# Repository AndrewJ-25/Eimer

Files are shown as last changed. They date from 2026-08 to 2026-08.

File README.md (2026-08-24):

# Eimer
Eimer is a wearable RP2040 devboard!

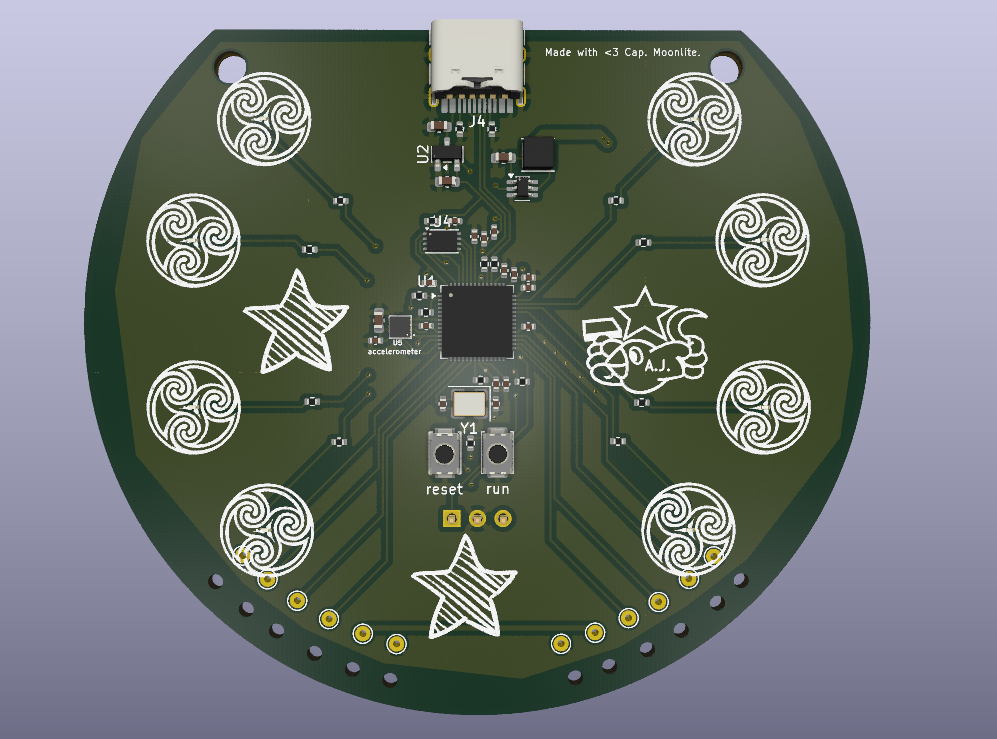
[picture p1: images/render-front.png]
front view

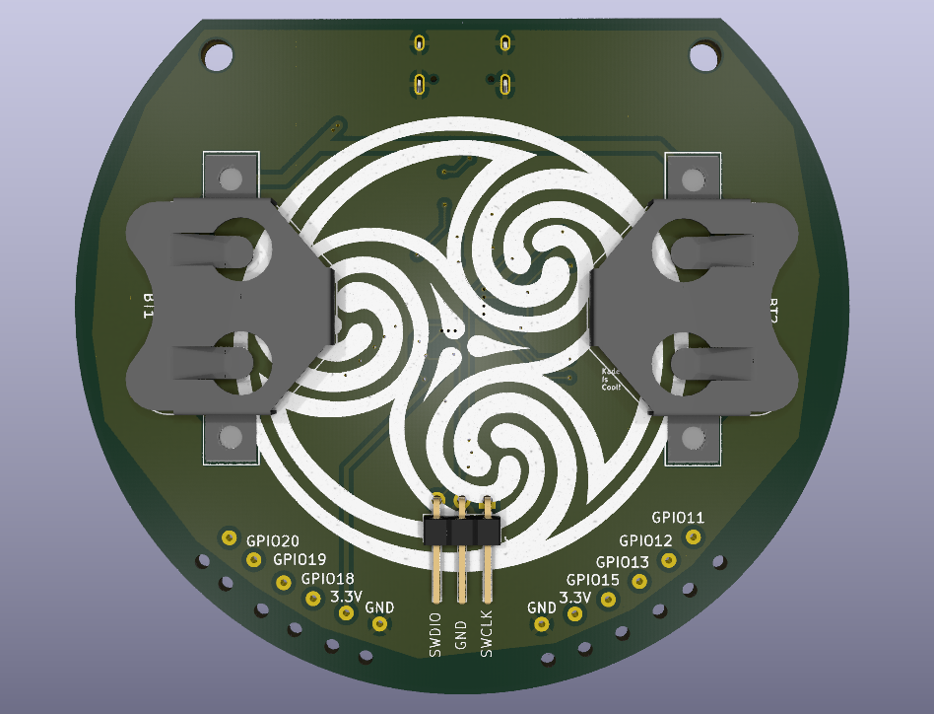
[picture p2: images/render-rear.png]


## Description and Features

A multi-axis accelerometer, 8 LEDs and 8 GPIO pads make Eimer an ideal wearable device. Solder pads are accompanied by holes to run the wire through, so there is no strain on the solder joint.

Eimer can be programmed using Arduino framework. Two mounting holes can be attached to a lanyard necklace, or safety pins.

Eimer can be powered with USB C or two CR2032 button cells (the board will work with one button cell, with a shorter battery life). Important note: do not plug in USB while cells are inserted!

I designed Eimer to get more comfortable with SMD and to learn more about MCUs. I started this project by following a tutorial posted in Hackclub Macondo before customising it.

The name comes from Irish mythology:)

## Assembly

All components can be soldered on a hotplate, except the coin cell holders which require hand-soldering.

## Schematic

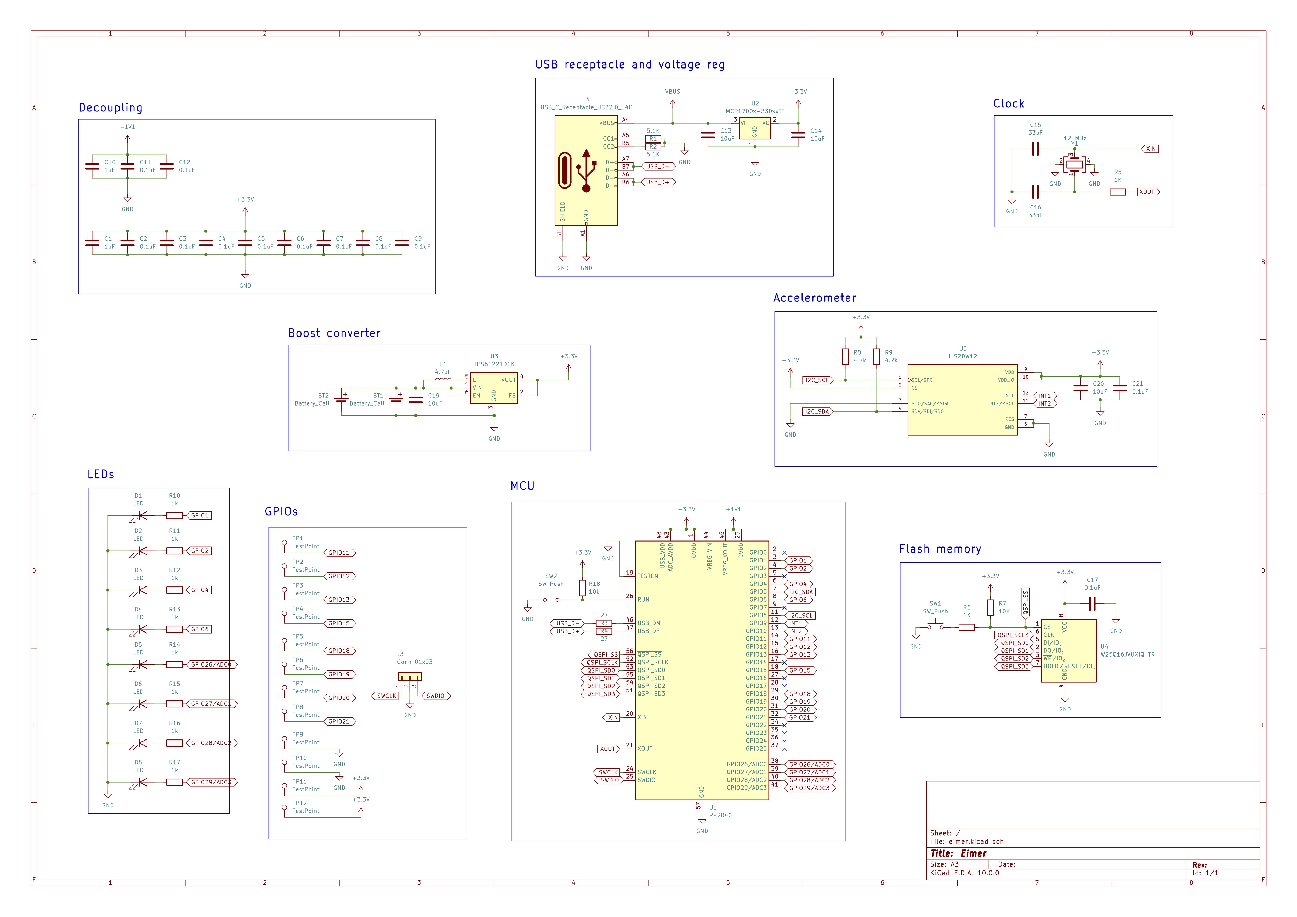
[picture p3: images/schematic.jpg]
schematic


## PCB

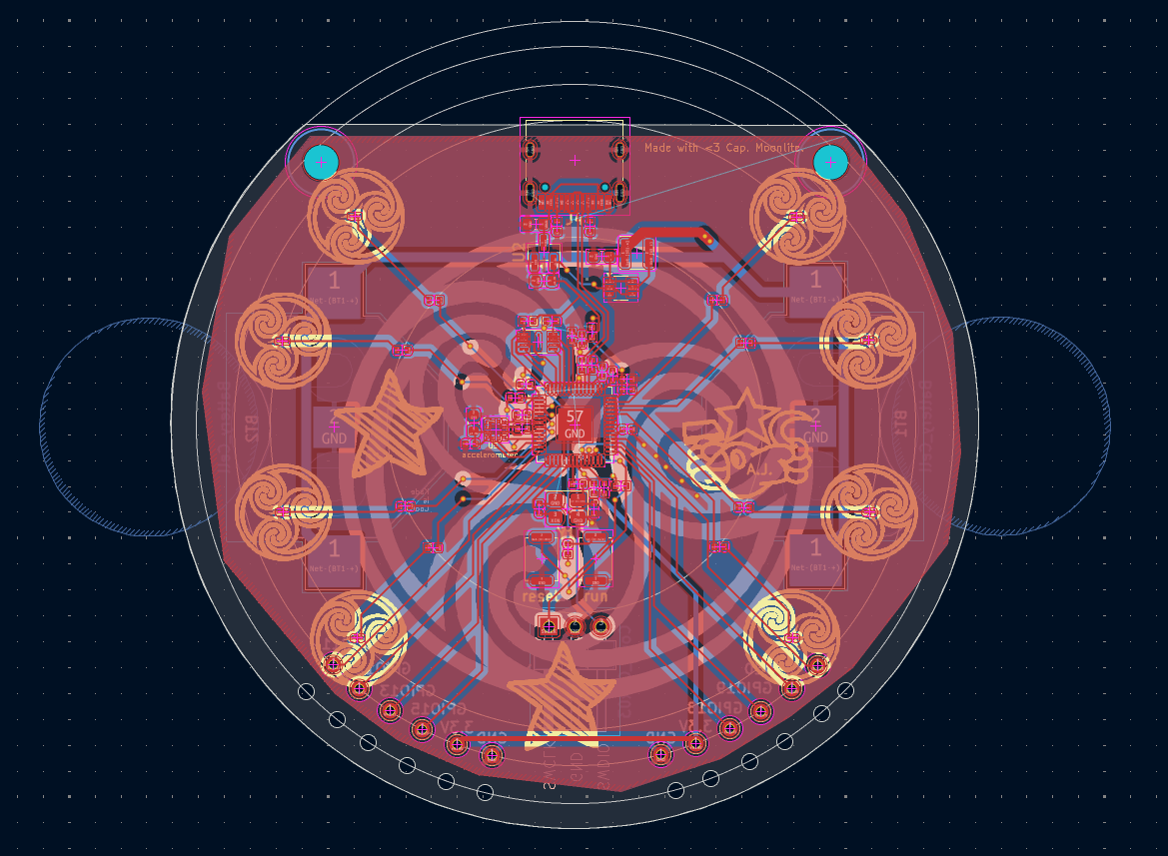
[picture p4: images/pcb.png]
pcb


## BOM

|Designator |Footprint |Quantity|Description|Suggested source|Total cost, £|
|---|---|---|---|---|--|
|BT1, BT2 |BatteryHolder_Multicomp_BC-2001_1x2032 |2 |CR2032 cell holder|https://www.aliexpress.com/item/1005010097971513.html|2.00|
|C1, C10 |0402 |2 |1uF capacitor|https://www.aliexpress.com/item/32435282135.html|0.67|
|C11, C12, C17, C2, C21, C3, C4, C5, C6, C7, C8, C9 |0402 |12 |0.1uF capacitor|https://www.aliexpress.com/item/32435282135.html|0.67
|C13, C14, C19, C20 |0603 |4 |10uF capacitor|https://www.aliexpress.com/item/1005007404529007.html|1.83|
|C15, C16 |0402 |2 |33pF capacitor|https://www.aliexpress.com/item/1005002960548572.html|1.27|
|D1, D2, D3, D4, D5, D6, D7, D8 |0201 |8 |LED green|https://www.aliexpress.com/item/1005007406675682.html|5.05|
|J3 |PinHeader_1x03_P2.54mm_Horizontal |1 |1x3 horizontal pin header| https://www.aliexpress.com/item/1005007569841697.html|0.55|
|J4 |USB_C_Receptacle_HRO_TYPE-C-31-M-12 |1 |USBC Receptacle|https://www.aliexpress.com/item/1005008805157100.html|1.04|
|L1 |L_APV_ANR3015 |1 |4.7uH inductor|https://www.aliexpress.com/item/1005001699576419.html|1.14|
|R1, R2 |0402 |2 |5.1K resistor|https://www.aliexpress.com/item/4001321720241.html (multipack includes all required resistor values)|1.86|
|R10, R11, R12, R13, R14, R15, R16, R17, R5, R6 |0402 |10 |1k resistor|-|-|
|R18, R7 |0402 |2 |10k resistor|-|-|
|R3, R4 |0402 |2 |27ohm resistor|-|-|
|R8, R9 |0402 |2 |4.7k resistor|-|-|
|RESET, RUN |SW_Push_SPST_NO_Alps_SKRK |2 |Push switch|https://jlcpcb.com/partdetail/XUNPU-TS_1088AR02016/C720477|1.00|
|U1 |QFN-56-1EP_7x7mm_P0.4mm_EP3.2x3.2mm |1 |RP2040 MCU chip|https://www.aliexpress.com/item/1005007275652762.html|3.46|
|U2 |SOT-23 |1 |MCP1700x-330xxTT voltage regulator|https://www.aliexpress.com/item/32808973510.html|0.99|
|U3 |Texas_R-PDSO-G6 |1 |TPS61221DCK boost converter|https://www.aliexpress.com/item/1005012857789997.html|3.69|
|U4 |Winbond_USON-8-1EP_3x2mm_P0.5mm_EP0.2x1.6mm|1 |W25Q16JVUXIQ TR flash memory|https://www.aliexpress.com/item/1005012822339773.html|5.55|
|U5 |LIS2DW12 |1 |LIS2DW12 accelerometer|https://www.aliexpress.com/item/1005009164629980.html|3.22|
|Y1 |Crystal_SMD_3225-4Pin_3.2x2.5mm |1 |12 MHz crystal|https://www.aliexpress.com/item/1005005409440787.html|2.50|
|PCB|-|1|PCB|https://jlcpcb.com/|2.95|
|Total| | | | |39.44|

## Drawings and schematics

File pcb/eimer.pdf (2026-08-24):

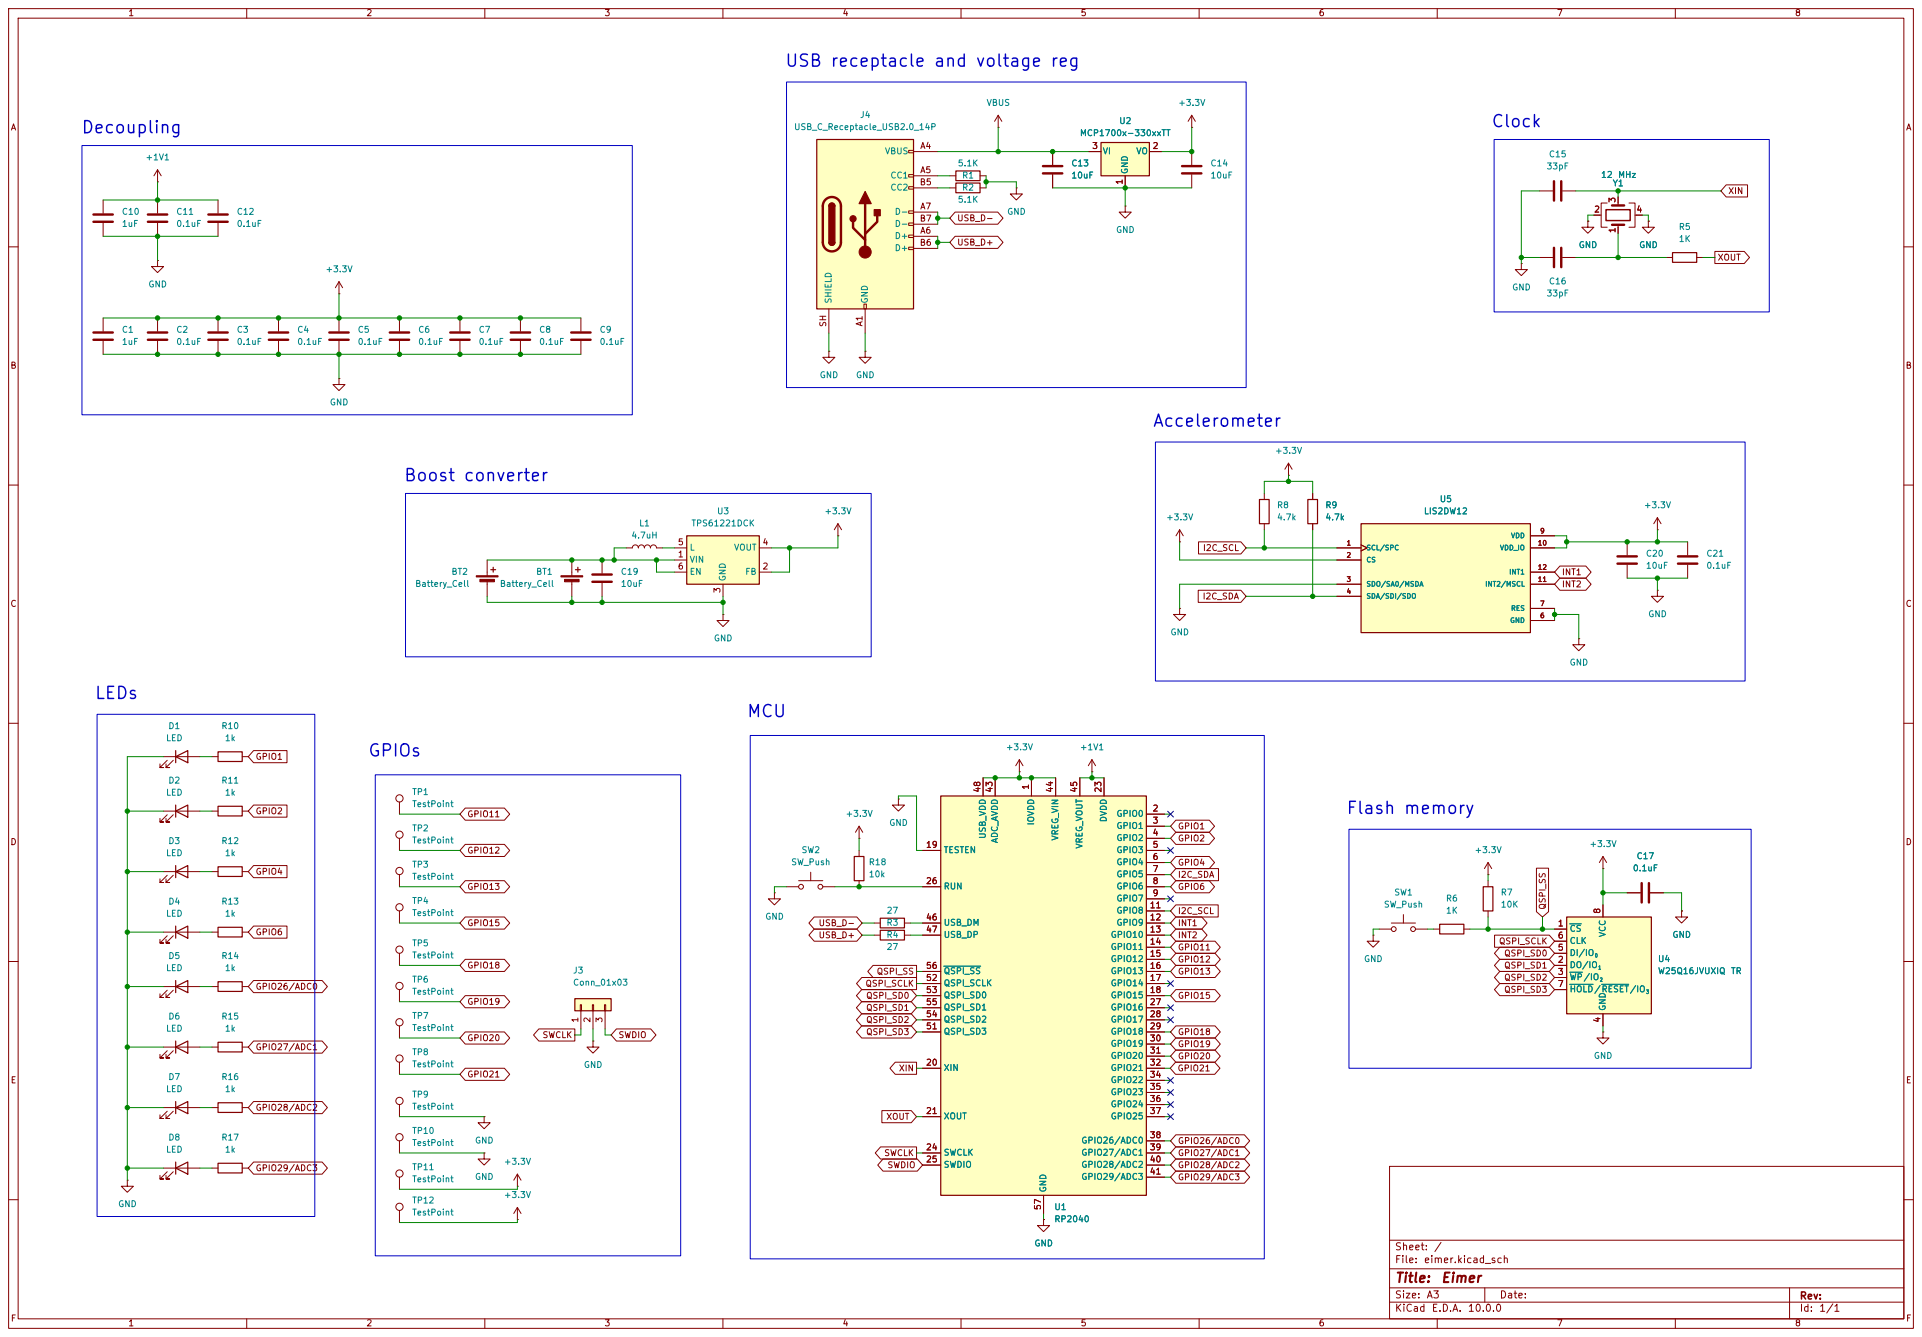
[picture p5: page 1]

USB receptacle and voltage reg

4 DI/IO0 5 CLK 6 HOLD/RESET/IO3 7 VCC

Size: A3 | Rev: | F Date:
KiCad E.D.A. 10.0.0 | Id: 1/1

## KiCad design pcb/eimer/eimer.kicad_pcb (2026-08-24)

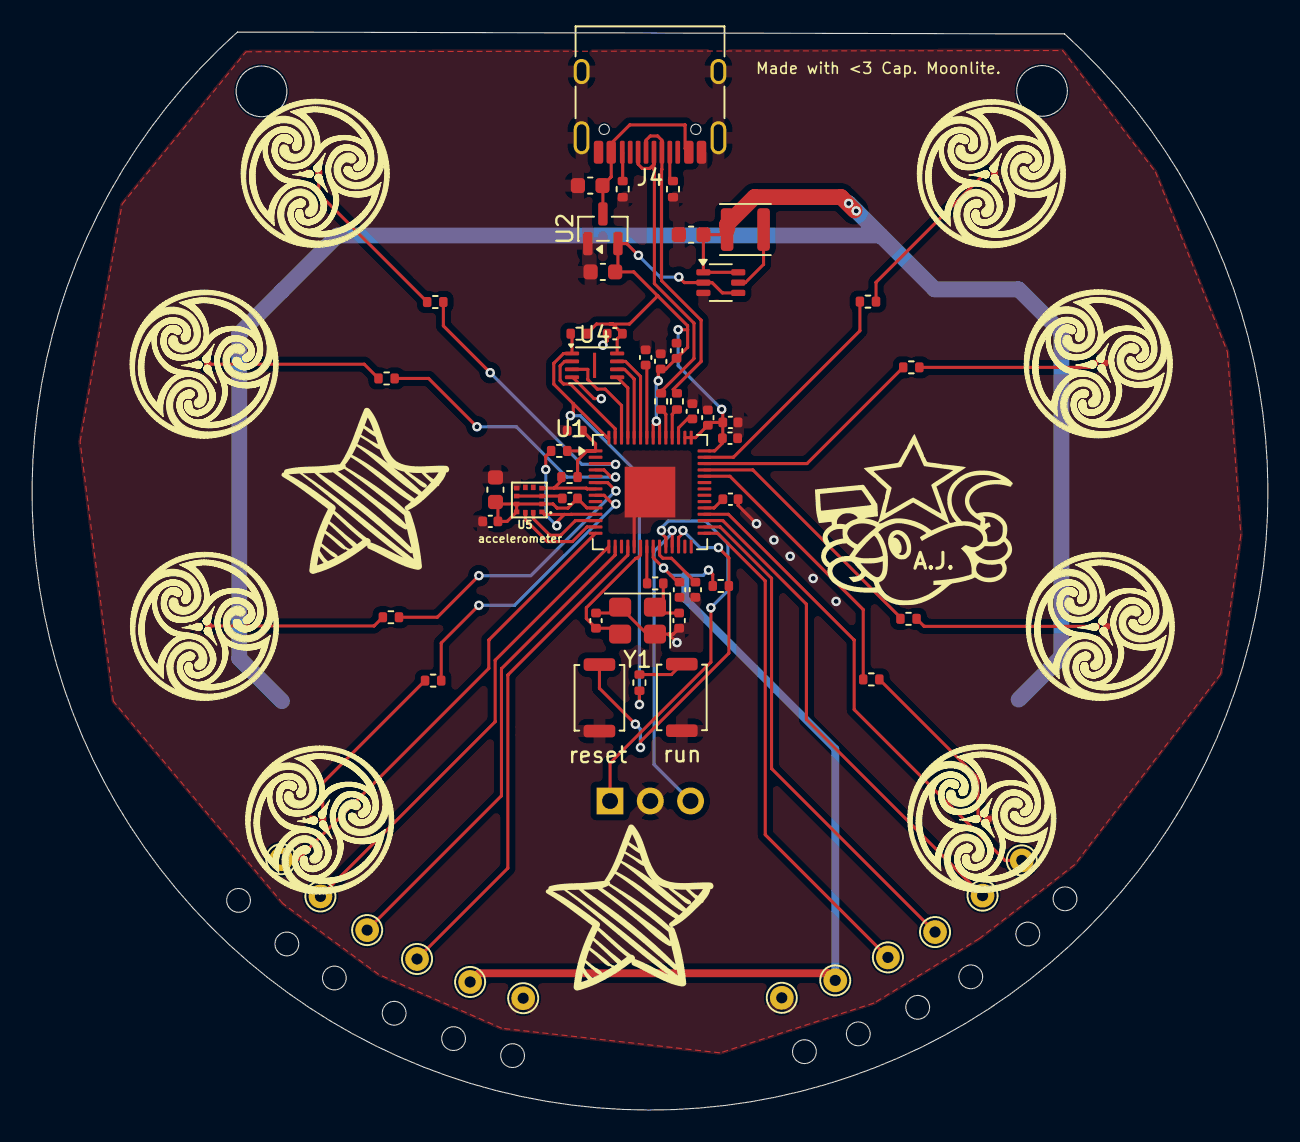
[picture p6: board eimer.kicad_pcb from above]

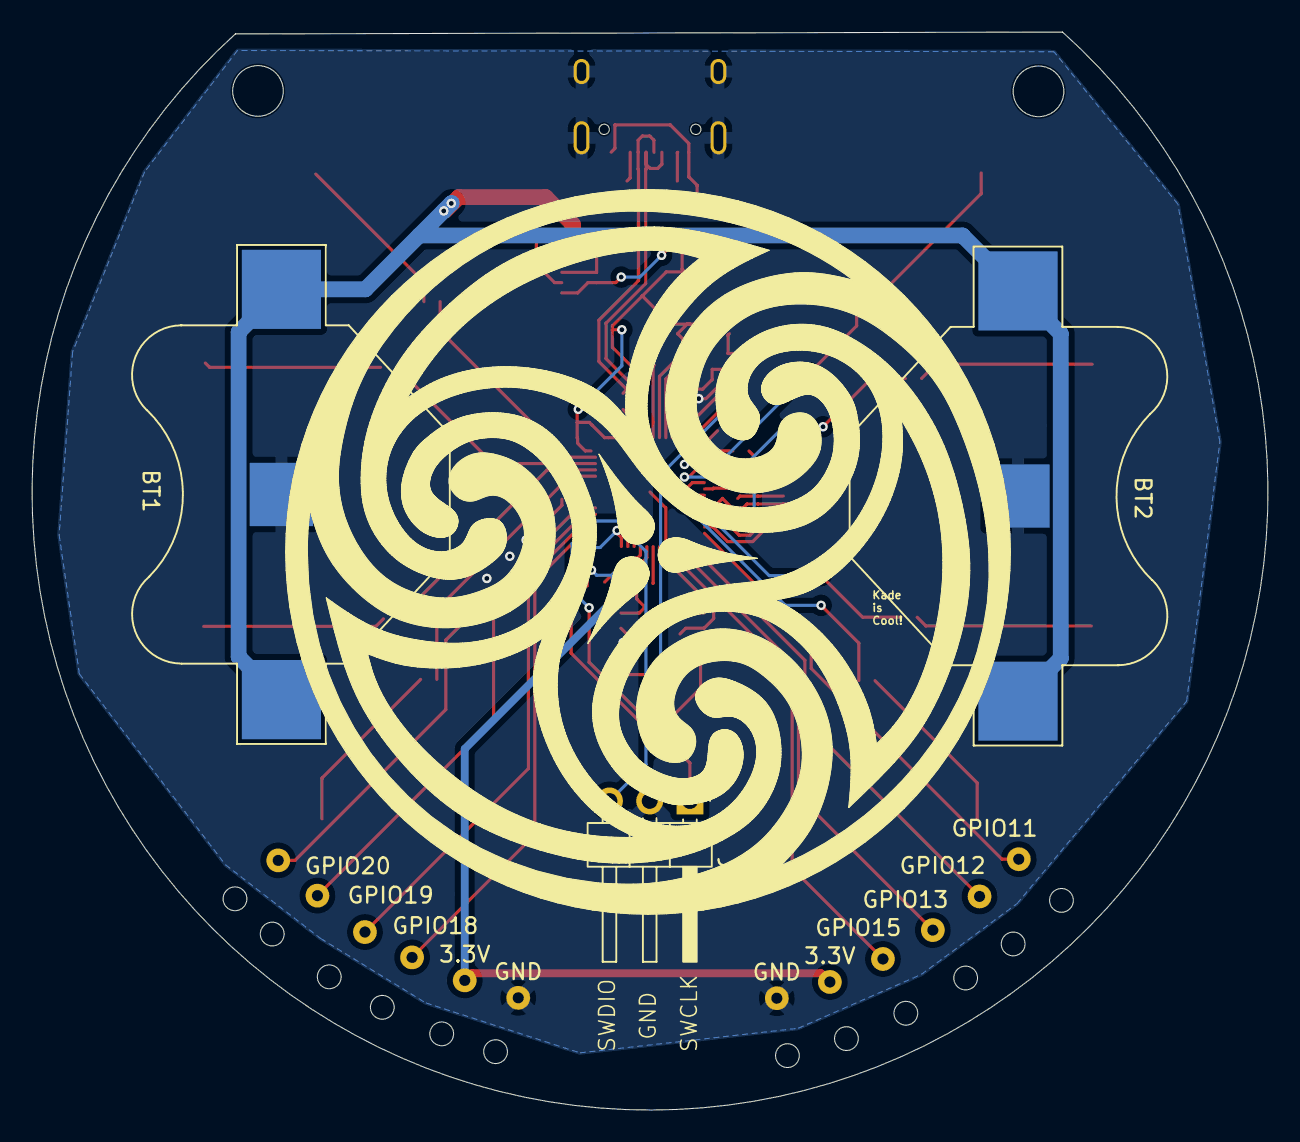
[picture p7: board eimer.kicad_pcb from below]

Board: 2 copper layers, 78.0 x 68.1 mm, 71 parts (3 on the bottom side), 53 nets.

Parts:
3.3V, 3.3V#2: TestPoint; TestPoint_THTPad_D1.5mm_Drill0.7mm
BT1, BT2: Battery_Cell; BatteryHolder_Multicomp_BC-2001_1x2032
C1, C10: 1uF; C_0402_1005Metric
C2, C3, C4, C5, C6, C7, C8, C9, C11, C12, C17, C21: 0.1uF; C_0402_1005Metric
C13, C14, C19, C20: 10uF; C_0603_1608Metric
C15, C16: 33pF; C_0402_1005Metric
D1, D2, D3, D4, D5, D6, D7, D8: LED; LED_0201_0603Metric
GND: TestPoint; TestPoint_THTPad_D1.5mm_Drill0.7mm
GND#2: TestPoint; TestPoint_THTPad_D1.5mm_Drill0.7mm
GPIO11, GPIO12, GPIO13, GPIO15, GPIO18, GPIO19, GPIO20, GPIO21: TestPoint; TestPoint_THTPad_D1.5mm_Drill0.7mm
J3: Conn_01x03; PinHeader_1x03_P2.54mm_Horizontal
J4: USB_C_Receptacle_USB2.0_14P; USB_C_Receptacle_HRO_TYPE-C-31-M-12
L1: 4.7uH; L_APV_ANR3015
R1, R2: 5.1K; R_0402_1005Metric
R3, R4: 27; R_0402_1005Metric
R5, R6: 1K; R_0402_1005Metric
R7: 10K; R_0402_1005Metric
R8, R9: 4.7k; R_0402_1005Metric
R10, R11, R12, R13, R14, R15, R16, R17: 1k; R_0402_1005Metric
R18: 10k; R_0402_1005Metric
U1: RP2040; QFN-56-1EP_7x7mm_P0.4mm_EP3.2x3.2mm
U2: MCP1700x-330xxTT; SOT-23
U3: TPS61221DCK; Texas_R-PDSO-G6
U4: W25Q16JVUXIQ TR; Winbond_USON-8-1EP_3x2mm_P0.5mm_EP0.2x1.6mm
U5: LIS2DW12; LIS2DS12
Y1: 12 MHz; Crystal_SMD_3225-4Pin_3.2x2.5mm
reset: SW_Push; SW_Push_SPST_NO_Alps_SKRK
run: SW_Push; SW_Push_SPST_NO_Alps_SKRK

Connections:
+1V1: C10.1, C11.1, C12.1, U1.23 (DVDD), U1.45 (VREG_VOUT), U1.50 (DVDD)
+3.3V: 3.3V.1 (1_1), 3.3V#2.1 (1_1), C1.1, C2.1, C3.1, C4.1, C5.1, C6.1, C7.1, C8.1, C9.1, C14.1, C17.1, C20.1, C21.1, R7.2, R8.1, R9.1, R18.1, U1.1 (IOVDD), U1.10 (IOVDD), U1.22 (IOVDD), U1.33 (IOVDD), U1.42 (IOVDD), U1.43 (ADC_AVDD), U1.44 (VREG_VIN), U1.48 (USB_VDD), U1.49 (IOVDD), U2.2 (VO), U3.2 (FB), U3.4 (VOUT), U4.8 (VCC), U5.2 (CS), U5.9 (VDD), U5.10 (VDD_IO)
GND: BT1.2 (-), BT2.2 (-), C1.2, C2.2, C3.2, C4.2, C5.2, C6.2, C7.2, C8.2, C9.2, C10.2, C11.2, C12.2, C13.2, C14.2, C15.1, C16.2, C17.2, C19.2, C20.2, C21.2, D1.1 (K), D2.1 (K), D3.1 (K), D4.1 (K), D5.1 (K), D6.1 (K), D7.1 (K), D8.1 (K), GND.1 (1_1), GND#2.1 (1_1), J3.2, J4.A1 (GND), J4.A12 (GND), J4.B1 (GND), J4.B12 (GND), J4.SH (SHIELD), R1.2, R2.1, U1.19 (TESTEN), U1.57 (GND), U2.1 (GND), U3.3 (GND), U4.4 (GND), U5.3 (SDO/SA0/MSDA), U5.6 (GND), U5.7 (RES), U5.8 (GND), Y1.2, Y1.4, reset.1, run.1
GPIO1: R10.2, U1.3 (GPIO1)
GPIO2: R11.2, U1.4 (GPIO2)
GPIO4: R12.2, U1.6 (GPIO4)
GPIO6: R13.2, U1.8 (GPIO6)
GPIO11: GPIO11.1 (1_1), U1.14 (GPIO11)
GPIO12: GPIO12.1 (1_1), U1.15 (GPIO12)
GPIO13: GPIO13.1 (1_1), U1.16 (GPIO13)
GPIO15: GPIO15.1 (1_1), U1.18 (GPIO15)
GPIO18: GPIO18.1 (1_1), U1.29 (GPIO18)
GPIO19: GPIO19.1 (1_1), U1.30 (GPIO19)
GPIO20: GPIO20.1 (1_1), U1.31 (GPIO20)
GPIO21: GPIO21.1 (1_1), U1.32 (GPIO21)
GPIO26/ADC0: R14.2, U1.38 (GPIO26/ADC0)
GPIO27/ADC1: R15.2, U1.39 (GPIO27/ADC1)
GPIO28/ADC2: R16.2, U1.40 (GPIO28/ADC2)
GPIO29/ADC3: R17.2, U1.41 (GPIO29/ADC3)
I2C_SCL: R8.2, U1.11 (GPIO8), U5.1 (SCL/SPC)
I2C_SDA: R9.2, U1.7 (GPIO5), U5.4 (SDA/SDI/SDO)
INT1: U1.12 (GPIO9), U5.12 (INT1)
INT2: U1.13 (GPIO10), U5.11 (INT2/MSCL)
unnamed: BT1.1 (+), BT2.1 (+), C19.1, L1.1, U3.1 (VIN), U3.6 (EN)
unnamed: C16.1, R5.1, Y1.1
unnamed: D1.2 (A), R10.1
unnamed: D2.2 (A), R11.1
unnamed: D3.2 (A), R12.1
unnamed: D4.2 (A), R13.1
unnamed: D5.2 (A), R14.1
unnamed: D6.2 (A), R15.1
unnamed: D7.2 (A), R16.1
unnamed: D8.2 (A), R17.1
unnamed: J4.A5 (CC1), R1.1
unnamed: J4.B5 (CC2), R2.2
unnamed: R6.1, run.2
unnamed: R18.2, U1.26 (RUN), reset.2
unnamed: R3.2, U1.46 (USB_DM)
unnamed: R4.1, U1.47 (USB_DP)
unnamed: L1.2, U3.5 (L)
QSPI_SCLK: U1.52 (QSPI_SCLK), U4.6 (CLK)
QSPI_SD0: U1.53 (QSPI_SD0), U4.5 (DI/IO_{0})
QSPI_SD1: U1.55 (QSPI_SD1), U4.2 (DO/IO_{1})
QSPI_SD2: U1.54 (QSPI_SD2), U4.3 (~WP/IO_{2})
QSPI_SD3: U1.51 (QSPI_SD3), U4.7 (~HOLD/~RESET/IO_{3})
QSPI_SS: R6.2, R7.1, U1.56 (~QSPI_SS), U4.1 (~CS)
SWCLK: J3.1, U1.24 (SWCLK)
SWDIO: J3.3, U1.25 (SWDIO)
USB_D+: J4.A6 (D+), J4.B6 (D+), R4.2
USB_D-: J4.A7 (D-), J4.B7 (D-), R3.1
VBUS: C13.1, J4.A4 (VBUS), J4.A9 (VBUS), J4.B4 (VBUS), J4.B9 (VBUS), U2.3 (VI)
XIN: C15.2, U1.20 (XIN), Y1.3
XOUT: R5.2, U1.21 (XOUT)

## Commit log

2026-07-16 start on schematic
    [eimer.kicad_pcb, eimer.kicad_sch]
2026-07-16 more work on schematic
    [eimer.kicad_sch]
2026-07-18 finished schematic according to guide
    [eimer.kicad_sch]
2026-07-18 assigned footprints according to docs
    [eimer.kicad_sch]
2026-07-18 started layout of pcb
    [eimer.kicad_pcb, eimer.kicad_sch]
2026-07-18 placed more caps
    [eimer.kicad_pcb]
2026-07-19 fixed power nets
    [eimer.kicad_sch]
2026-07-21 go to shleeep
    [eimer.kicad_pcb]
2026-07-23 differential pais ahhhh
    [eimer.kicad_pcb]
2026-07-29 more routing
    [eimer.kicad_pcb]
2026-07-30 routed left hand side gpios
    [eimer.kicad_pcb]
2026-07-30 routed left hand gpios
    [eimer.kicad_pcb]
2026-08-23 finished schematic for wearable mcu
    [eimer.kicad_pcb, eimer.kicad_sch]
2026-08-23 assigned footprints
    [eimer.kicad_sch]
2026-08-23 almost finished routing
    [freerouting.dsn]
2026-08-24 routing leds
    [eimer.kicad_pcb, eimer.kicad_sch]
2026-08-24 routed left leds again
    [eimer.kicad_pcb]
2026-08-24 routed all left side gpios
    [eimer.kicad_pcb, eimer.kicad_sch]
2026-08-24 routed all gpios
    [eimer.kicad_pcb, eimer.kicad_sch]
2026-08-24 poured ground plane
    [eimer.kicad_pcb]
2026-08-24 finished all routing
    [eimer.kicad_pcb]
2026-08-24 removed some silkscreen text
    [eimer.kicad_pcb, eimer.kicad_sch]
2026-08-24 applied silkscreen art
    [eimer.kicad_pcb]
2026-08-24 generated gerbers
    [bom.csv, designators.csv, eimer.kicad_pcb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]
2026-08-24 tidy repo
    [eimer.kicad_pcb, eimer.kicad_sch, freerouting.dsn]
2026-08-24 Revise BOM with updated sources and prices
    Updated component sources and costs in BOM table.
2026-08-24 Revise BOM with detailed component descriptions
    Updated BOM with additional details and sources for components.
    [bom.csv]
2026-08-24 Include schematic and PCB sections in README
    Added schematic and PCB images to the README.
